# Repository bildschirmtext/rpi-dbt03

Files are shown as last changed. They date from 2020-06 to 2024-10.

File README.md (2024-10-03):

# rpi-dbt03
Hardware, Software and Firmware for a Raspberry Pi to DBT-03 adapter

There is now a possibility to directly patch a Bookworm Raspbian image.

Run `./patch_image.sh <imagename>` as root. It only works on uncompressed images. You can then `dd` that image onto your SD-card or use the Raspberry Pi Imager. The later also allows you to set settings.
The image will reboot multiple times.

The boot partition can also hold a `btx_config.txt` file where you can configure the host to connect to.

```
BTX_HOST=btx.clarke-3.de
BTX_PORT=20000
```

## Old way of installing it

On the Raspberry PI check out this repository. 

Install the packages in install-packages.sh (run it as root). 

Enable spi with raspi-config. 

Change the baudrate of the programmer "linuxspi" to a smaller value 40000 is OK. This setting is found in /etc/avrdude.conf

This currently is still incomplete.

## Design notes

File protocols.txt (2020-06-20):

SPI-Protocol
============

SPI is a synchronous serial protocol, therefore on every cycle a bit is transmitted. If the Master sends an octet, the Slave will also send an octet.

In this project commands and responses have 3 octets each:

Master -> Slave: $ff CMD PAR $FF $FF
Slave -> Master: XXX $AA STA STB RES

XXX: Undefined
$FF: All bits set
$AA: Hex AA can be used to detect ATMega
CMD: Command octet
	$02: write octet into buffer towards terminal
		PAR: octet to be written to terminal
		RES: number of free octets in write buffer or $ff for error
	$03: read from Terminal 
		RES: received octet or $ff in case of error
		STB: number of bits in buffer or $ff if nothing there
	$04: set tone
		PAR=$01: silent (level 0, this is not the idle between octets)
		PAR=$02: 425 Hz (used during connection)
		PAR=$03: 1300 Hz (used during connection)
		PAR=$04: switch to data mode
	$05: set LED
		Bits 0-1: Number of the LED
		Bits 2-7: State of the LED in each one of the 6 phases
	$06: get free octets of buffer to terminal
STA: Status A
	Bit 7: Octet to be read from terminal
  	Bit 6: Free space in buffer to terminal
  	Bit 5: More than 8 octets free in buffer
  	Bit 4: S input 1=> Terminal wants to dial
	Bit 0: always on
STB: Status B: depends on command

DBT-03 Protocol
================
1. Terminal legt S auf 5V
2. Modem legt 425 Hz auf ED (ca 1s)
3. Modem legt ED auf 5V (ca 2s)
4. Modem legt ED auf 425 Hz (ca 0.5s)
5. Modem legt ED auf 5V (ca 0.5s)
6. Modem legt ED auf 1300 Hz (ca 0.5s)
7. Modem legt ED auf Daten 1=>0V 0=>5V
8. Terminal legt Daten auf SD: 1=>5V 0=>0V

Somit ist der Idlezustand der Datenphase ED auf 0V (=>1). Die Daten müssen mit 1200bps 8N1 übertragen werden.
SD enthält die Sendedaten. Hier ist der 1=>5V 0=>0V. Somit ist die Leitung im Idlezustand bei 5V.

Das Interface scheint auf Optokoppler im Modem ausgelegt zu sein. Somit sollte ED im Terminal mit einem Pull-Up ausgestattet sein, und S und SD sollten in der Lage sein ein paar Milliampere für die Sendedioden liefern können. In echten Modems wird so die Potentialfreiheit sichergestellt. Anderweitig könnten sonst gefährliche Spannungen anliegen oder zumindest Brummschleifen entstehen.

IP Protocol
============
This protocol is spoken on the IP end of things. Essentially when the Terminal starts a connection by putting S to 5V, a TCP/IP connection will be made to a server. Octets will be exchanged transparently.

Optional parts:
When a 0 octet is received via IP, the output buffer will be discarded. This allows to react quickly to user input while a page is being transmitted. This could, for example be sent before a new page is transmitted after user input.
Data units that are not supported by BTX terminals could be filtered out.
Maybe we could have a special data unit sent from the server to disconnect from that server and re-connect to a new server.

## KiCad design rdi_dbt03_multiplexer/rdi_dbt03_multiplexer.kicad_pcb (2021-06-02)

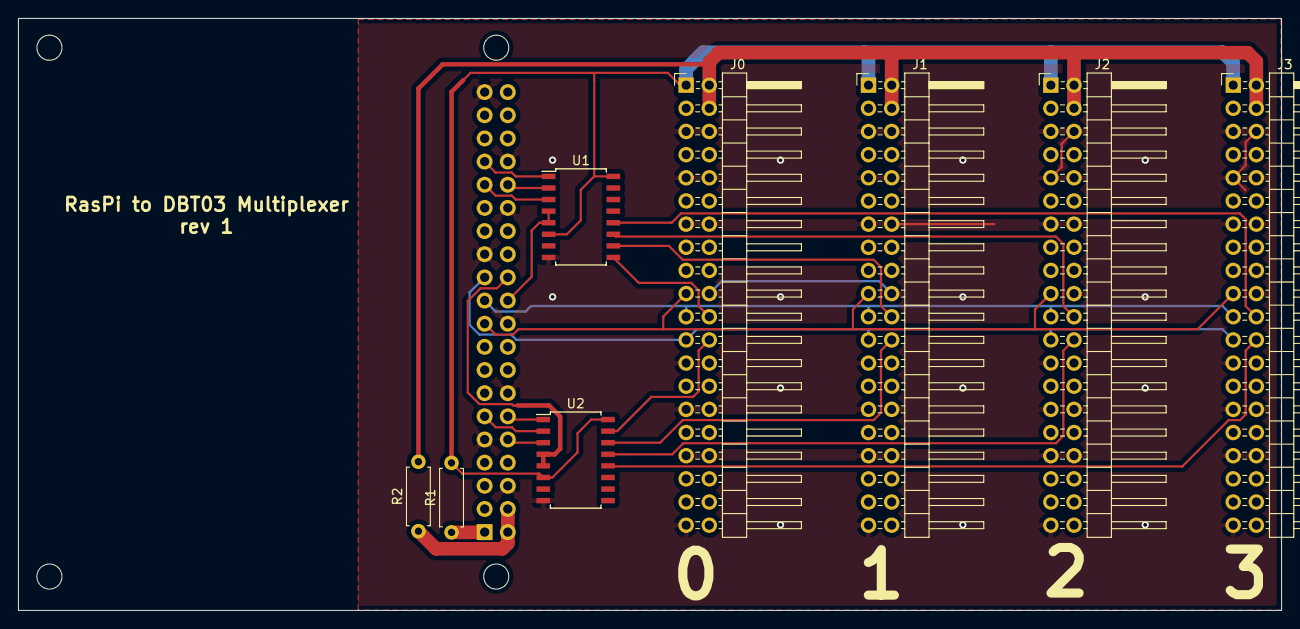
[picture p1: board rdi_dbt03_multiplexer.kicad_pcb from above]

Board: 2 copper layers, 138.5 x 64.9 mm, 9 parts (1 on the bottom side), 24 nets.

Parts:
J0, J1, J2, J3: Conn_02x20_Odd_Even; Pin_Header_Angled_2x20_Pitch2.54mm
R1, R2: 0r; R_Axial_DIN0207_L6.3mm_D2.5mm_P7.62mm_Horizontal
RP1: Raspberry_Pi_2_3; raspberrypi_2_3
U1, U2: 74LS138; SOIC-16W_5.3x10.2mm_Pitch1.27mm

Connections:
/A0: RP1.12, U2.1
/A1: RP1.11, U2.2
/A2: RP1.10, U2.3
/B0: RP1.33, U1.1
/B1: RP1.32, U1.2
/B2: RP1.31, U1.3
/E5V: J0.2, J0.4, J1.2, J1.4, J2.2, J2.4, J3.2, J3.4, R2.2
/MISO: J0.21, J1.21, J2.21, J3.21, RP1.21
/MOSI: J0.19, J1.19, J2.19, J3.19, RP1.19
/RST_N: RP1.22, U1.4, U1.5
/RST_N0: J0.22, U1.9
/RST_N1: J1.22, U1.10
/RST_N2: J2.22, U1.11
/RST_N3: J3.22, U1.12
/SCK: J0.23, J1.23, J2.23, J3.23, RP1.23
/SPI_CS: RP1.24, U2.4, U2.5
/SPI_CS0: J0.24, U2.15
/SPI_CS1: J1.24, U2.14
/SPI_CS2: J2.24, U2.13
/SPI_CS3: J3.24, U2.12
GND: J0.5, J0.6, J0.9, J0.10, J0.13, J0.14, J0.20, J0.25, J0.29, J0.30, J0.33, J0.34, J0.39, J1.5, J1.6, J1.9, J1.10, J1.13, J1.14, J1.20, J1.25, J1.29, J1.30, J1.33, J1.34, J1.39, J2.5, J2.6, J2.9, J2.10, J2.13, J2.14, J2.20, J2.25, J2.29, J2.30, J2.33, J2.34, J2.39, J3.5, J3.6, J3.9, J3.10, J3.13, J3.14, J3.20, J3.25, J3.29, J3.30, J3.33, J3.34, J3.39, RP1.6, RP1.9, RP1.14, RP1.20, RP1.25, RP1.30, RP1.34, RP1.39, U1.8, U2.8
unnamed: R1.1, RP1.1
unnamed: R2.1, RP1.2, RP1.4
VCC: J0.1, J1.1, J2.1, J3.1, R1.2, U1.6, U1.16, U2.6, U2.16

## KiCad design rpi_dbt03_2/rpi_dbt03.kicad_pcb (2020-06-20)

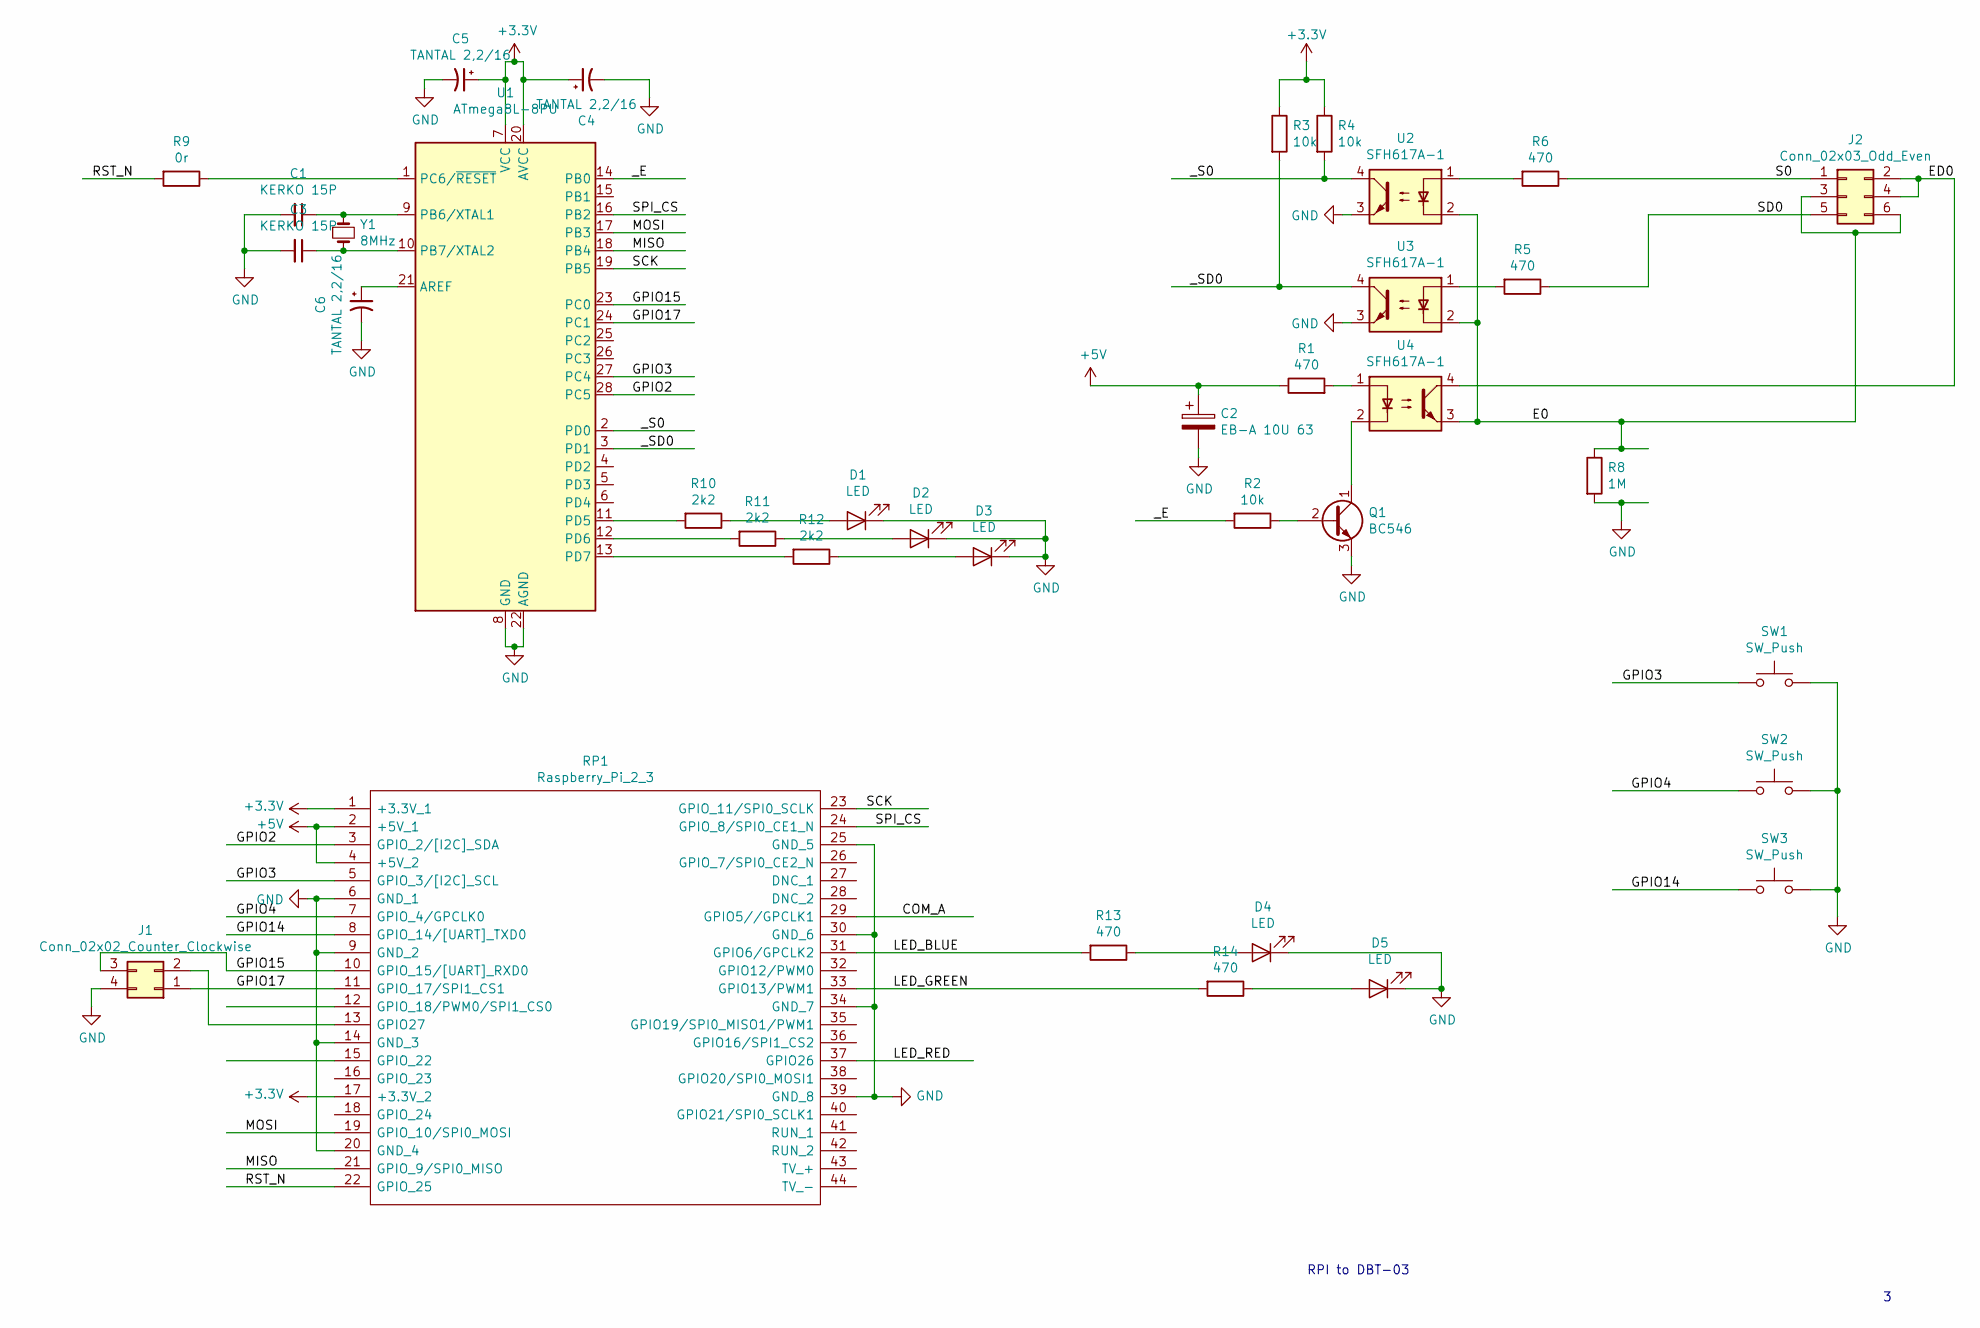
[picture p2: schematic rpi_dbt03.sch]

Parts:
C1, C3: KERKO 15P; C_Disc_D3.0mm_W1.6mm_P2.50mm
C2: EB-A 10U 63; CP_Radial_D5.0mm_P2.50mm
C4, C5: TANTAL 2,2/16; CP_Radial_Tantal_D4.5mm_P2.50mm
C6: TANTAL 2,2/16; C_Disc_D3.0mm_W2.0mm_P2.50mm
D1, D2, D3, D4, D5: LED; LED_D3.0mm
J1: Conn_02x02_Counter_Clockwise; Pin_Header_Straight_2x02_Pitch2.54mm
J2: Conn_02x03_Odd_Even; Pin_Header_Straight_2x03_Pitch2.54mm
Q1: BC546; TO-92_Inline_Wide
R1, R5, R6, R13, R14: 470; R_Axial_DIN0207_L6.3mm_D2.5mm_P7.62mm_Horizontal
R2, R3, R4: 10k; R_Axial_DIN0207_L6.3mm_D2.5mm_P7.62mm_Horizontal
R8: 1M; R_Axial_DIN0207_L6.3mm_D2.5mm_P7.62mm_Horizontal
R9: 0r; R_Axial_DIN0207_L6.3mm_D2.5mm_P7.62mm_Horizontal
R10, R11, R12: 2k2; R_Axial_DIN0207_L6.3mm_D2.5mm_P7.62mm_Horizontal
RP1: Raspberry_Pi_2_3; raspberrypi_2_3; Manufacturer_Part_Number Raspberry Pi 2 or 3
SW1, SW2, SW3: SW_Push; SW_PUSH_6mm
U1: ATmega8L-8PU; DIP-28_W7.62mm
U2, U3, U4: SFH617A-1; DIP-4_W7.62mm_Socket_LongPads
Y1: 8MHz; Crystal_HC49-4H_Vertical

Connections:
+3V3: C4.1, C5.1, R3.1, R4.1, RP1.1 (+3.3V_1), RP1.17 (+3.3V_2), U1.7 (VCC), U1.20 (AVCC)
+5V: C2.1, R1.1, RP1.2 (+5V_1), RP1.4 (+5V_2)
/E0: J2.3, J2.6, R8.1, U2.2, U3.2, U4.3
/ED0: J2.2, J2.4, U4.4
/GPIO2: RP1.3 (GPIO_2/[I2C]_SDA), U1.28 (PC5)
/GPIO3: RP1.5 (GPIO_3/[I2C]_SCL), SW1.1, U1.27 (PC4)
/GPIO4: RP1.7 (GPIO_4/GPCLK0), SW2.1
/GPIO14: RP1.8 (GPIO_14/[UART]_TXD0), SW3.1
/GPIO15: J1.3, RP1.10 (GPIO_15/[UART]_RXD0), U1.23 (PC0)
/GPIO17: J1.1, RP1.11 (GPIO_17/SPI1_CS1), U1.24 (PC1)
/LED_BLUE: R13.2, RP1.31 (GPIO6/GPCLK2)
/LED_GREEN: R14.2, RP1.33 (GPIO13/PWM1)
/MISO: RP1.21 (GPIO_9/SPI0_MISO), U1.18 (PB4)
/MOSI: RP1.19 (GPIO_10/SPI0_MOSI), U1.17 (PB3)
/RST_N: R9.2, RP1.22 (GPIO_25)
/S0: J2.1, R6.1
/SCK: RP1.23 (GPIO_11/SPI0_SCLK), U1.19 (PB5)
/SD0: J2.5, R5.1
/SPI_CS: RP1.24 (GPIO_8/SPI0_CE1_N), U1.16 (PB2)
/_E: R2.2, U1.14 (PB0)
/_S0: R4.2, U1.2 (PD0), U2.4
/_SD0: R3.2, U1.3 (PD1), U3.4
GND: C1.2, C2.2, C3.2, C4.2, C5.2, C6.2, D1.1 (K), D2.1 (K), D3.1 (K), D4.1 (K), D5.1 (K), J1.4, Q1.3 (E), R8.2, RP1.6 (GND_1), RP1.9 (GND_2), RP1.14 (GND_3), RP1.20 (GND_4), RP1.25 (GND_5), RP1.30 (GND_6), RP1.34 (GND_7), RP1.39 (GND_8), SW1.2, SW2.2, SW3.2, U1.8 (GND), U1.22 (AGND), U2.3, U3.3
unnamed: C1.1, U1.9 (PB6/XTAL1), Y1.1
unnamed: C3.1, U1.10 (PB7/XTAL2), Y1.2
unnamed: C6.1, U1.21 (AREF)
unnamed: D1.2 (A), R10.1
unnamed: D2.2 (A), R11.1
unnamed: D3.2 (A), R12.1
unnamed: D4.2 (A), R13.1
unnamed: D5.2 (A), R14.1
unnamed: J1.2, RP1.13 (GPIO27)
unnamed: Q1.1 (C), U4.2
unnamed: Q1.2 (B), R2.1
unnamed: R1.2, U4.1
unnamed: R5.2, U3.1
unnamed: R6.2, U2.1
unnamed: R9.1, U1.1 (PC6/~RESET)
unnamed: R10.2, U1.11 (PD5)
unnamed: R11.2, U1.12 (PD6)
unnamed: R12.2, U1.13 (PD7)

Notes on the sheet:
RPI to DBT-03

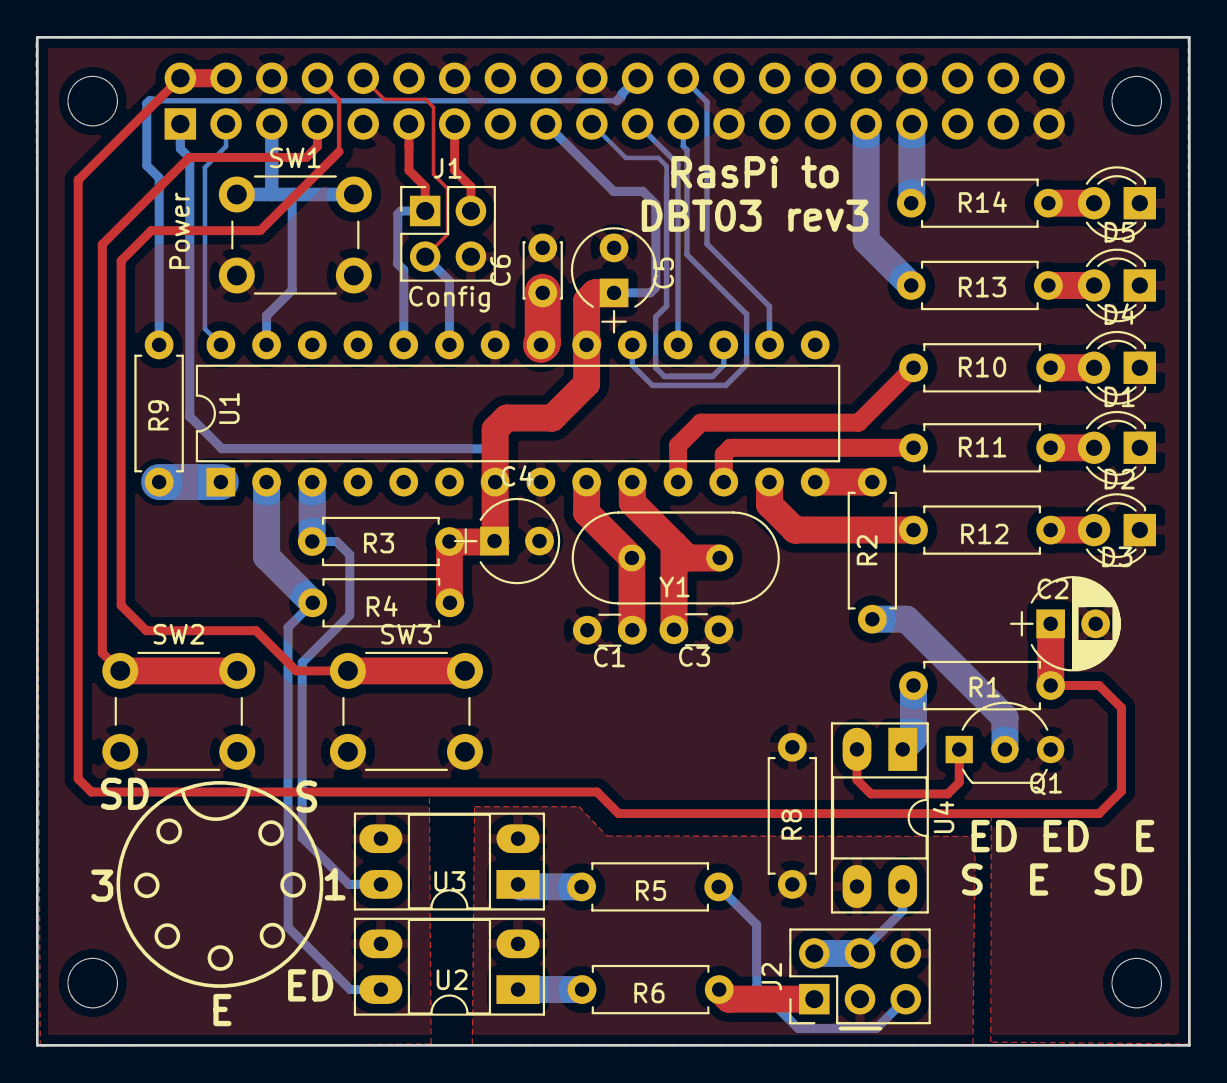
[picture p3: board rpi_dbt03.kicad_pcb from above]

Board: 2 copper layers, 64.0 x 56.0 mm, 36 parts (0 on the bottom side), 41 nets.

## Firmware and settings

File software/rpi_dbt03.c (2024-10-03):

#include <stdint.h>
#include <unistd.h>
#include <stdio.h>
#include <stdlib.h>
#include <getopt.h>
#include <fcntl.h>
#include <sys/ioctl.h>
#include <linux/types.h>
#include <linux/spi/spidev.h>
#include <string.h>
#include <strings.h>
#include <sys/socket.h>
#include <sys/types.h>
#include <netinet/in.h>
#include <netdb.h>
#include <stdio.h>
#include <string.h>
#include <stdlib.h>
#include <unistd.h>
#include <errno.h>
#include <arpa/inet.h> 


#define PIN_LED_BLUE 6 
#define PIN_LED_GREEN 13
#define PIN_RESET 25

#define ARRAY_SIZE(a) (sizeof(a) / sizeof((a)[0]))
int open_spi();
void close_spi(int);


#define SA struct sockaddr


static const char *device = "/dev/spidev0.0";

#define SPILEN (5)

uint16_t spi_transfer(int fd, const uint8_t cmd, const uint16_t par, uint8_t *result)
{
	uint8_t tx[SPILEN] = {0xff, 0x00, 0x00, 0x00, 0x00};

	tx[1]=cmd;
	tx[2]=(par & 0xff);
	tx[3]=(par >>8 )&0xff;

	uint8_t rx[SPILEN] = {0x00, 0x00, 0x00, 0x00, 0x00};
	struct spi_ioc_transfer tr = {
		.tx_buf = (unsigned long)tx,
		.rx_buf = (unsigned long)rx,
		.len = SPILEN,
		.delay_usecs = 0,
		.speed_hz = 0,
		.bits_per_word = 8,
	};

	int res = ioctl(fd, SPI_IOC_MESSAGE(1), &tr);
	if (res < 1) return -1;

/*	int n;
	printf(">");
	for (n=0; n<SPILEN; n++) {
		printf("%02x ", tx[n]);
	}
	printf("\n<");
	for (n=0; n<SPILEN; n++) {
		printf("%02x ", rx[n]);
	}
	printf("\n");*/
	if (result!=NULL) *result=rx[4];
	return rx[2] | (rx[3]<<8);
}


int set_mcu_led(int fd, const int led, const int state)
{
	if (led<0) return -1;
	if (led>2) return -1;
	return spi_transfer(fd, 0x05, ((state&0x3f)<<2)|led, NULL); 
}

int set_tone(int fd, const int tone)
{
	if (tone<1) return -1;
	if (tone>4) return -1;
	return spi_transfer(fd, 0x04, tone, NULL);
}

int send_octet(int fd, const int octet, uint8_t *res)
{
	if (octet<0) return -1;
	if (octet>255) return -1;
	return spi_transfer(fd, 0x02, octet, res);
}

int get_free_octets(int fd)
{
	uint8_t res=0;
	spi_transfer(fd, 0x06, 0x00, &res);
	return res&0x7f;
}

int read_octet(int fd, uint8_t *res)
{
	return spi_transfer(fd,0x03, 0, res);
}

int open_spi()
{
	int fd=open(device, O_RDWR);
	if (fd<0) return fd;

	int ret=0;

	int mode=0;
	ret = ioctl(fd, SPI_IOC_WR_MODE, &mode);
	if (ret == -1) return ret;
	ret = ioctl(fd, SPI_IOC_RD_MODE, &mode);
	if (ret == -1) return ret;

	int bits=8;
	ret = ioctl(fd, SPI_IOC_WR_BITS_PER_WORD, &bits);
	if (ret == -1) return ret;
	ret = ioctl(fd, SPI_IOC_RD_BITS_PER_WORD, &bits);
	if (ret == -1) return ret;

	int speed=50000;
	ret = ioctl(fd, SPI_IOC_WR_MAX_SPEED_HZ, &speed);
	if (ret == -1) return ret;
	ret = ioctl(fd, SPI_IOC_RD_MAX_SPEED_HZ, &speed);
	if (ret == -1) return ret;
	return fd;
}

void close_spi(int fd)
{
	close(fd);
}

void set_gpio(const int no, const int value)
{
	char cmd[128];
	memset(cmd, 0, sizeof(cmd));
	snprintf(cmd, sizeof(cmd)-1, "/usr/bin/gpioset 0 %d=%d", no, value%2);
	system(cmd);
}

void set_leds(int led)
{
	set_gpio(PIN_LED_BLUE, (led>>0)%2);
	set_gpio(PIN_LED_GREEN, (led>>1)%2);
}


/* Initialize the terminal and wait for it to start*/
int term_start(int fd)
{
	int n=0;
	int s=0;
	set_leds(0x01);
	set_tone(fd, 1); //Silence
	printf("Waiting for S to go low\n");
	//If S is high (terminal picked up) wait for it to go now)
	while (s!=0) {
		int status=set_mcu_led(fd, 1, n); //Make LED 1 on the MCU blink
		if (n==0) n=0x3f; else n=0;
		usleep(250000);
		s=(status>>4)&0x01;
	}
	set_mcu_led(fd, 1, 0); //Turn of LED 1 on the MCU
	usleep(250000);

	printf("Waiting for S to go high\n");
	while (s==0) {
		int status=set_mcu_led(fd, 0, n); //Make LED 0 on the MCU blink
		if (n==0) n=0x3f; else n=0;
		usleep(250000);
		s=(status>>4)&0x01;
	}
	set_mcu_led(fd, 0, 0); //Turn of LED 0 on the MCU
	set_tone(fd, 2); //440Hz 
	return 0;
}

/* Acknowledge the connection */
int term_constart(int fd)
{
	int status=set_mcu_led(fd, 0, 0x15);
	if (((status>>4)&0x01)==0) return -1;
	status=set_tone(fd, 2); //440 Hz
	if (((status>>4)&0x01)==0) return -1;
	usleep(1000000);
	status=set_tone(fd, 1);
	if (((status>>4)&0x01)==0) return -1;
	usleep(2000000);
	status=set_tone(fd, 2);
	if (((status>>4)&0x01)==0) return -1;
	usleep( 500000);
	status=set_tone(fd, 3);
	if (((status>>4)&0x01)==0) return -1;
	usleep(1000000);
	status=set_tone(fd, 4);
	if (((status>>4)&0x01)==0) return -1;
	status=set_mcu_led(fd, 0, 0);
	if (((status>>4)&0x01)==0) return -1;
	usleep(1000000);
	return 0;
}

int do_connect(const char *hostname, const int port)
{
        struct hostent *h=gethostbyname(hostname);
        if (h==NULL) {
                fprintf(stderr, "Couldn't resolve hostname %s\n", hostname);
                return -1;
        }
        int sockfd=socket(h->h_addrtype, SOCK_STREAM, 0);
        if (sockfd==-1) return sockfd;
        fprintf(stderr, "do_connect %s %d\n", hostname, port);
        if (h->h_addrtype==AF_INET) {
                struct sockaddr_in servaddr;
                memset(&servaddr, 0, sizeof(servaddr));
                servaddr.sin_family=AF_INET;
                memcpy(&(servaddr.sin_addr.s_addr), h->h_addr, 4);
                servaddr.sin_port=htons(port);
                if (connect(sockfd, (SA*)&servaddr, sizeof(servaddr))!=0) {
                        fprintf(stderr, "Couldn't connect to %s:%d\n", hostname, port);
                        return -1;
                }
        }
        struct timeval tv;
        tv.tv_sec=0;
        tv.tv_usec=40*1000;
        setsockopt(sockfd, SOL_SOCKET, SO_RCVTIMEO, (const char*)&tv, sizeof tv);
        return sockfd;
}



void reset_mcu()
{
	printf("Reset MCU...");
	set_gpio(PIN_RESET, 0);
	usleep(200000);
	set_gpio(PIN_RESET, 1);
	usleep(500000);
	printf("done\n");
}

int handle_socket_to_term(int fd, int sock_fd)
{
	int status=0;
	char buf[8];
	int l=read(sock_fd, buf, sizeof(buf));
	if (l<0) { //Some socket error, probably connection broke
		if (errno==EAGAIN) return 0;
		printf("Error : read Failed  %d (%s)\n", errno, strerror(errno));
		return -1;
	}
	if (l>0) {
		uint8_t res=0;
		int n;
		for (n=0; n<l; n++) {
			status=send_octet(fd, buf[n], &res);
			if ( ((status>>4)&0x01)==0) {
				return -1;
			}
		}
	}
	return 0;
}


int handle_term_to_socket(int fd, int sock_fd)
{
	uint8_t oct=0;
	int status=read_octet(fd, &oct);
	if ( ((status>>4)&0x01)==0) {
		return -1;
	}
	if (oct!=0xff) {
		char buf[1];
		buf[0]=oct;
		write(sock_fd, buf, 1);
	}
	return 0;
}

int socket_term_loop(int fd, int sock_fd)
{
	int status=0;
	while (0==0) {
		int bf=get_free_octets(fd);
		if (bf<=31) {
			status=set_mcu_led(fd, 1, 0x3f);
			if (((status>>4)&0x01)==0) return -1;
		} else {
			status=set_mcu_led(fd, 1, 0);
			if (((status>>4)&0x01)==0) return -1;
		}
		if (bf>8) {
			status=handle_socket_to_term(fd, sock_fd);
			if (status<0) return status;
		}
		status=handle_term_to_socket(fd, sock_fd);
		if (status<0) return status;
		usleep(10000);
	}
}


int main(int argc, char *argv[])
{
	int fd=open_spi();
	if (fd<0) {
		printf("couldn't open device\n");
		return 1;
	}

	char c_string[128];
	char *connection=NULL;
	
	FILE *cf=fopen("/boot/btx_ip.txt","r");
	if (cf==NULL) {
		if (argc!=3) {
			printf("Usage: %s <ip> <port>\n", argv[0]);
			return 1;
		}
		connection=argv[1];
	} else {
		memset(c_string, 0, sizeof(c_string));
		fread(c_string, sizeof(c_string)-1, 1, cf);
		connection=c_string;
		fclose(cf);
	}

	term_start(fd);

	int sock_fd=do_connect(connection, atoi(argv[2]));
	if (fd<0) {
		reset_mcu();
		return 1;
	}

	term_constart(fd);

	
	socket_term_loop(fd, sock_fd);
	reset_mcu();

	close(fd);
	return 0;
}

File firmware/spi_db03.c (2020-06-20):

#define F_CPU 8000000UL

#include <avr/io.h>
#include <util/delay.h>
#include <avr/interrupt.h>
#include <avr/sleep.h>
#include <stdint.h>
#include <string.h>


//LEDs

#define LED_STAT_CNT (6)
//LED Modes
#define LED_ON (0x3f)
#define LED_OFF (0x00)
#define LED_BLINK (0x07)
#define LED_FAST (0x2A)
#define LED_PHASE_1 (0x24)
#define LED_PHASE_2 (LED_PHASE_1<<2)
#define LED_PHASE_3 (LED_PHASE_1<<4)

#define DIV_1200HZ (6666)
#define DIV_850HZ (9412)
#define DIV_2600HZ (3076)

uint8_t led_stat[LED_STAT_CNT];
uint8_t led_phase=0;


inline void set_term_mode(int mode);

inline void set_led_ports(uint8_t bits)
{
	PORTD=(PORTD & 0x1f) | ((bits&0x7)<<5);
}

ISR(TIMER0_OVF_vect) //Will be called with 7812 Hz
{
	sei(); //Enable Interrupts again so this interrupt can be preempted
	led_phase=led_phase+1;
	if (led_phase>=LED_STAT_CNT) led_phase=0;
	set_led_ports(led_stat[led_phase]);
}


inline void set_led_status_phase(uint8_t phase, uint8_t led, int8_t status)
{
	if (phase>=LED_STAT_CNT) return;
	uint8_t map=(1<<led);
	if (status==0) { //LED off
		led_stat[phase]=led_stat[phase] & (~map);
	} else { //LED on
		led_stat[phase]=led_stat[phase] | (map);
	}
}

inline void set_led_status(uint8_t led, int8_t status)
{
	if (led>2) return;
	int n;
	for (n=0; n<LED_STAT_CNT; n++) {
		set_led_status_phase(n, led, status & 0x01);
		status=status>>1;
	}
}

void init_led()
{
	//set LED variables
	int8_t n;
	for (n=0; n<LED_STAT_CNT; n++) led_stat[n]=0;
	//Init ports
	DDRD=DDRD | (0xe0);
	//init timer to 8MHz/1024=7812Hz
	TCCR0= (1<<CS02)|(1<<CS00);       // Start Timer 0 with prescaler 1024
	TIMSK= TIMSK|(1<<TOIE0);                // Enable Timer 0 overflow interrupt
	sei();      
	//Prescaler /256 
}



// Buffer
#define BSIZE (32)

typedef struct {
	uint8_t write_pointer;
	uint8_t read_pointer;
	uint8_t buffer[BSIZE];
} buffer_t;

inline void clear_buffer(buffer_t *b)
{
	if (b==NULL) return;
	memset(b, 0, sizeof(buffer_t));
}

inline int get_from_buffer(buffer_t *b)
{
	if (b->write_pointer==b->read_pointer) return -1;
	uint8_t v=b->buffer[b->read_pointer];
	b->buffer[b->read_pointer]=0;
	b->read_pointer=(b->read_pointer+1)%BSIZE;
	return v;
}


/*Returns the number of octets in the buffer */
inline int8_t buffer_used(buffer_t *b)
{
	if (b->write_pointer==b->read_pointer) return 0;
	if (b->write_pointer>b->read_pointer) return b->write_pointer-b->read_pointer;
	return b->write_pointer+BSIZE-b->read_pointer;
}

inline int8_t write_to_buffer(buffer_t *b, uint8_t v)
{
	if ((b->write_pointer+1)%BSIZE==b->read_pointer) return -1; //Buffer full
	b->buffer[b->write_pointer]=v;
	b->write_pointer=(b->write_pointer+1)%BSIZE;
	return buffer_used(b);
}


buffer_t rpi_to_term;
buffer_t term_to_rpi;

inline uint8_t get_status()
{
	uint8_t bits=0;
	if (buffer_used(&term_to_rpi)>0) bits=bits | (1<<7);
	if (buffer_used(&rpi_to_term)<BSIZE/2) bits=bits | (1<<6);
	if (buffer_used(&rpi_to_term)<BSIZE-8) bits=bits | (1<<5);
	//PD0 low => bit 4 high
	if ((PIND&0x01)==0) bits=bits | (1<<4);
	return bits;
}

/*spi_protocol
 * MOSI $ff cmd par $ff $ff
 * SOMI und und sta stb res
 *
 * par: parameter octet
 * und: undefined
 * sta: status octet A
 * 	Bit 7: Octet from terminal
 * 	Bit 6: Free space in buffer to terminal
 * 	Bit 5: More than 8 octets free in buffer
 * 	Bit 4: S input 1=> Terminal wants to dial
 * 	Bit 0: always 1
 * stb: status octet B
 * res: result / read data
 * cmd=$01 reset, par undefined
 * cmd=$02 write, parameter octet to Write
 * 	res=$ff: write error
 * 	res=<=BSIZE: free octets in write buffer
 * cmd=$03 read, parameter undefined, res=octet
 * cmd=$04 set tone
 * 	par=$01: silent
 * 	par=$02: 440 Hz
 * 	par=$03: 1700 Hz
 * 	par=$04: set to data
 * cmd=0x05 set LEDs
 * 	par:
 * 	  Bit 0-1: LED Number
 * 	  Bit 2-7: LED Pattern
 */

/*spi_state 
 * 	0: idle waiting for command
 *	1-2: receive parameters
 *	3: wait for $ff
 */
#define SPILEN (4)
uint8_t spi_state=0xff;

uint8_t rx[SPILEN]; //Received octets
uint8_t tx[SPILEN]; //Octets to send

ISR(SPI_STC_vect)
{
	//read from SPI to spi_in
	uint8_t spi_in=SPDR; 
	if ( (spi_state>=SPILEN)) {
		if (spi_in==0xff) {
			SPDR=0xAA;
			spi_state=0;
			//fill status octets
			tx[0]=get_status(); //STA
			tx[1]=0x55; //STB
			tx[2]=0xAA; //Result
		}
		return;
	}

	//Store incoming byte and send outgoing byte (this is the timing critical stuff
	rx[spi_state]=spi_in;
	SPDR= tx[spi_state];
	sei(); //enable interrupts from here
	//This should be completed within a single SPI clock cycle
	

	//if first octet is in the command range go to spi_state=1
	if ((spi_state==0)) {
		uint8_t cmd=rx[0];
		if (cmd==0x03) { //read command
			int res=get_from_buffer(&term_to_rpi);
			if (res<0) {
				tx[1]=0xff;
				tx[2]=0xff;
			} else {
				tx[1]=buffer_used(&term_to_rpi);
				tx[2]=res;
			}
		}
		spi_state=1;
		return;
	}

	//Handle parameter octet then go to spi_state=2
	if (spi_state==1) {
		uint8_t cmd=rx[0];
		uint8_t par=rx[1];
		if (cmd==0x02) { //write command
			int8_t res=write_to_buffer(&rpi_to_term, spi_in);
			if (res<0) {
				tx[2]=0xff;
			} else {
				tx[2]=BSIZE-res;
			}
		}
		if (cmd==0x04) { //set tone
			set_term_mode(par);
			tx[2]=0xAA;
		}
		if (cmd==0x05) { //set LED
			set_led_status((par & 0x03), par>>2);
			tx[2]=0xAA;
		}
		if (cmd==0x06) { //read number of free octets in output buffer
			tx[2]=(BSIZE-buffer_used(&rpi_to_term))|0x80; //set bit 7 to avoid 0
		}
		spi_state=2;
		return;
	}

	if (spi_state==2){
		spi_state=3;
		return;
	}
	if (spi_state==3){
		spi_state=0xff;
		return;
	}
}

void init_spi()
{
	//init SPI
	SPCR=(1<<SPIE) | (1<<SPE);
	DDRB=DDRB| (1<<4);
}


//interface towards Terminal


int8_t term_uart_bit=-1;
int8_t term_uart_phase=0;
uint8_t term_uart_inb=0;

inline void term_in_uart(int8_t i)
{
	//If in the idle state and there is a one bit continue. Otherwise return
	if (term_uart_bit<0) {
		if (i!=0) return;
		term_uart_bit=0;
		term_uart_phase=0;
		term_uart_inb=0;
		return;
	}
	term_uart_phase=term_uart_phase+1;
	if (term_uart_phase>=16) {
		term_uart_bit=term_uart_bit+1;
		if (term_uart_bit>9) term_uart_bit=-1; //After stop bit, go to idle
		term_uart_phase=0;
	}
	if (term_uart_phase==7) { //Middle of a bit
		if (term_uart_bit==0) { //Start bit
			if (i!=0) { //if Start bit is not 0 => framing error
				term_uart_bit=-1;
				term_uart_phase=-1;
			}
		} else if (term_uart_bit==9) { //Stop bit
			if (i==1) { //if correct, write to buffer
				write_to_buffer(&term_to_rpi, term_uart_inb);				
			}
		} else { //Data bit
			term_uart_inb=(term_uart_inb >> 1) | (i<<7); 
		}
	}
}

int8_t term_state=0;
uint8_t term_outb=0;
/* term_state:
 * 	0: idle state 
 *	-1: beep state 1
 *	-2: beep state 2
 *	-3: high idle state (in between tones)
 */

inline void set_ed_line(uint8_t bit)
{
	PORTB=(PORTB & 0xfe) | (bit&0x01);
}
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

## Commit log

2020-02-22 Get SPI-Communication and LEDs running. Please make sure to patch your hardware to the new revision that is coming up.
2020-02-22 Found a hardware Bug. Pin 18 of the ATMega8 needs to connected to Pin 24 of the Raspberry PI. This will mean that a new layout is needed, however so far you can patch it by adding one bodge wire.
    [rpi_dbt03.kicad_pcb, rpi_dbt03.sch]
2020-02-24 Added SPI_CE line and swapped incorrectly named _SD0 and _S0 netw
    [rpi_dbt03.kicad_pcb, rpi_dbt03.sch]
2020-02-26 First "release" of the SPI protocoll
2020-02-29 Minor change, I think 2 network names have been swapped
    [rpi_dbt03.kicad_pcb]
2020-03-02 Fixed the frequencies according to official documentation
    [spi_db03.c]
2020-06-20 Version 3 which adds 3 buttons and some configuration jumpers
    [rpi_dbt03.kicad_pcb, rpi_dbt03.sch]
2024-09-29 Add binary and boot config line
    [config_clean.txt]
